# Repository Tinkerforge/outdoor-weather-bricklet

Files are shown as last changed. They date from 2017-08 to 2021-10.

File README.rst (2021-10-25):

Outdoor Weather Bricklet
========================

This repository contains the firmware source code and the hardware design
files. The documentation generator configs can be found at
https://github.com/Tinkerforge/generators

Repository Content
------------------

software/:
 * examples/: Examples for all supported languages
 * build/: Compiled files
 * src/: Source code of firmware
 * Makefile: Makefile to build project

hardware/:
 * Contains KiCad project files and additionally schematics as PDF

datasheets/:
 * Contains datasheets for sensors and complex ICs that are used

Hardware
--------

The hardware is designed with the open source EDA Suite KiCad
(http://www.kicad.org). Before you are able to open the files,
you have to install the Tinkerforge kicad-libraries
(https://github.com/Tinkerforge/kicad-libraries). You can either clone
them directly in hardware/ or clone them in a separate folder and
symlink them into hardware/
(ln -s kicad_path/kicad-libraries project_path/hardware). After that you
can open the .pro file in hardware/ with KiCad and from there view and
modify the schematics and the PCB layout.

Software
--------

If you want to do your own Brick/Bricklet firmware development we highly
recommend that you use our build environment setup script and read the
tutorial (https://www.tinkerforge.com/en/doc/Tutorials/Tutorial_Build_Environment/Tutorial.html).

To compile the C code we recommend you to install the newest GNU Arm Embedded
Toolchain (https://launchpad.net/gcc-arm-embedded/+download).
You also need to install bricklib2 (https://github.com/Tinkerforge/bricklib2).

You can either clone it directly in software/src/ or clone it in a
separate folder and symlink it into software/src/
(ln -s bricklib_path/bricklib2 project_path/software/src/). Finally make sure to
have CMake installed (http://www.cmake.org/cmake/resources/software.html).

After that you can build the firmware by invoking make in software/.
The firmware (.zbin) can then be found in software/build/ and uploaded
with brickv (click button "Flashing" on start screen).

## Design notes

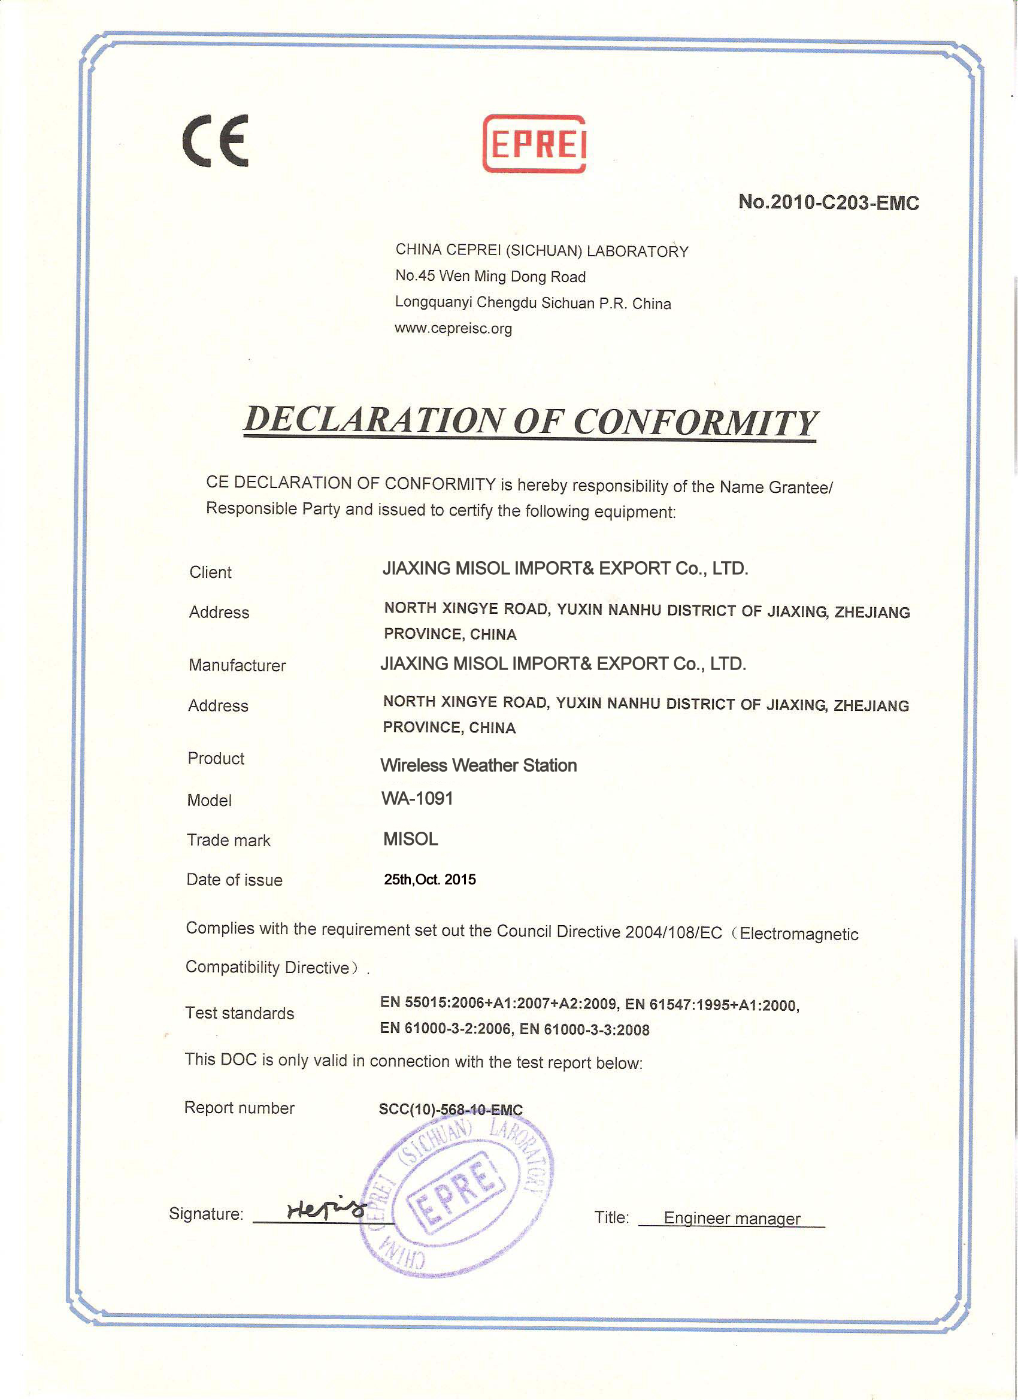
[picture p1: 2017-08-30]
datasheets/CE.jpg

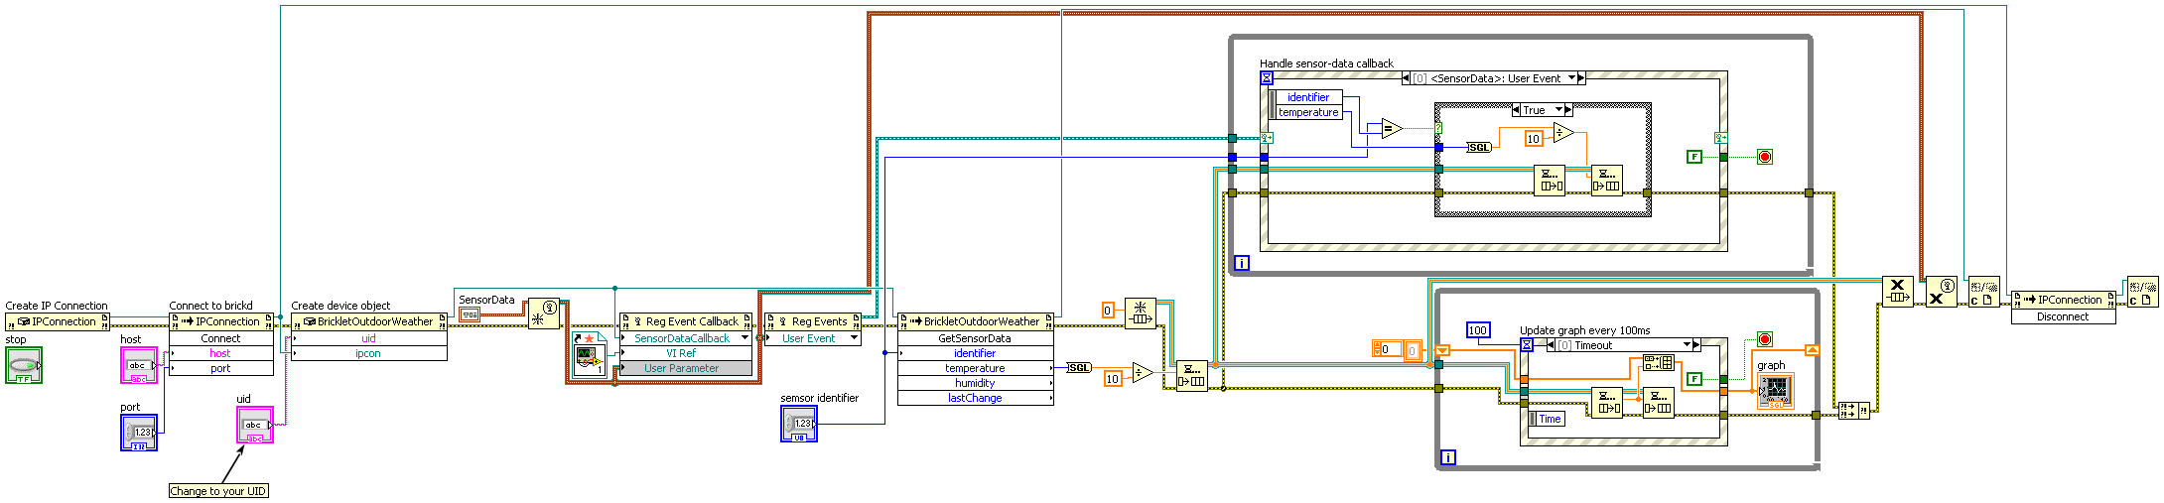
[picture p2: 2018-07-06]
software/examples/labview/Example Graph.vi.png

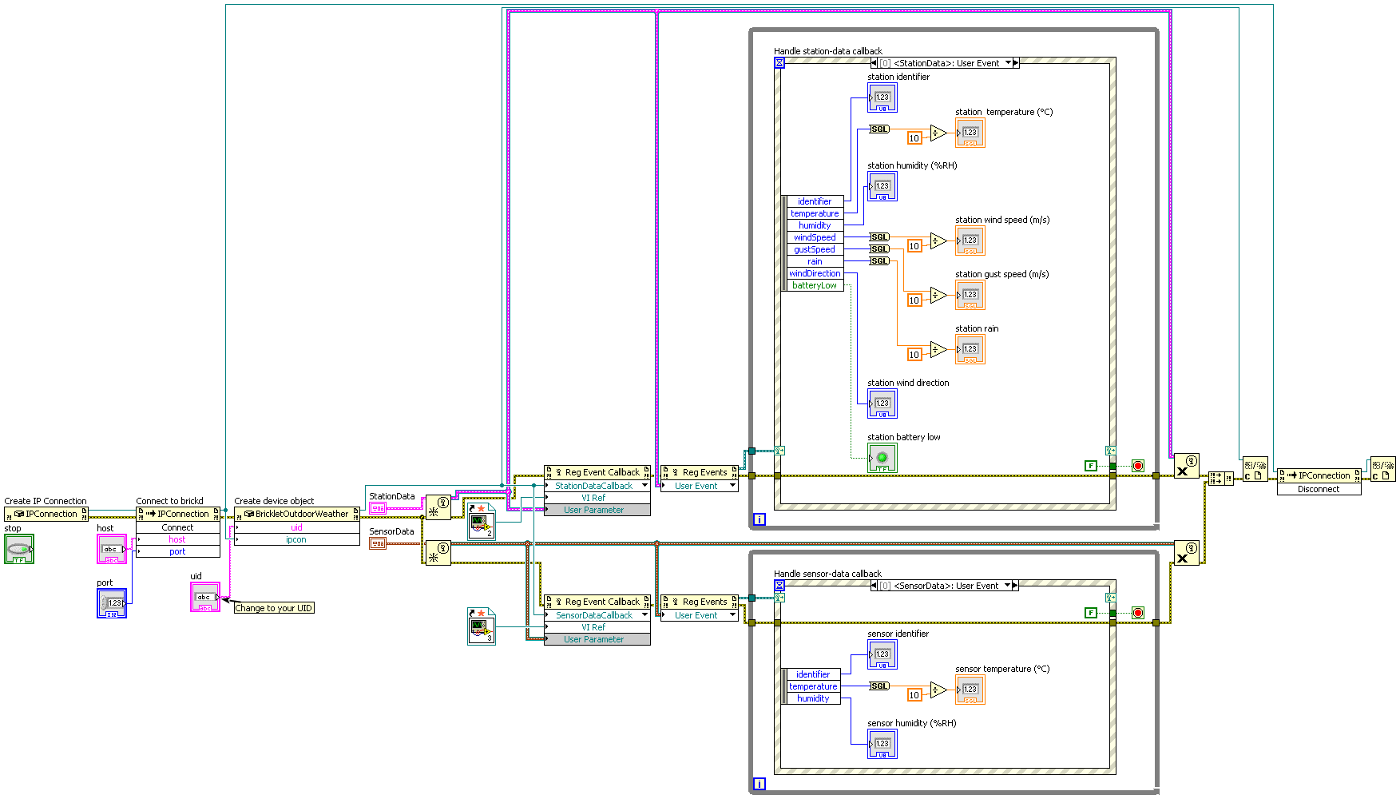
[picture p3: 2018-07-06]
software/examples/labview/Example Callback.vi.png

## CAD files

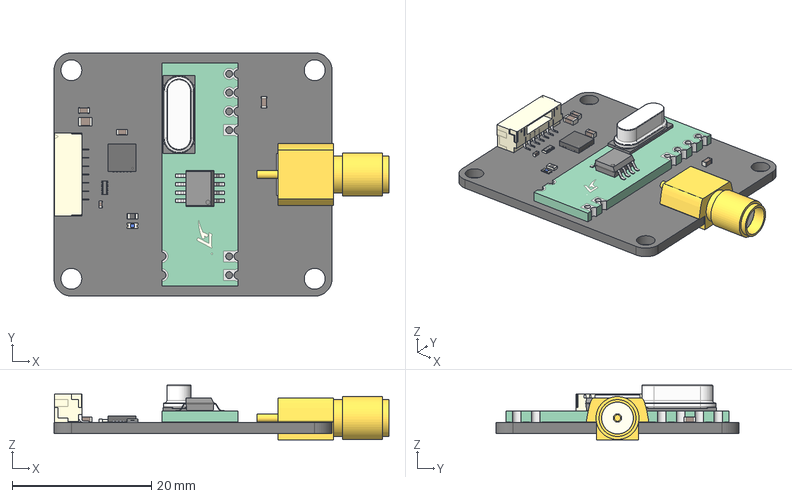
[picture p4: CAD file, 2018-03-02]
hardware/outdoor-weather.step
48.2 x 35.0 x 7.89 mm

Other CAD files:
hardware/outdoor-weather.FCStd

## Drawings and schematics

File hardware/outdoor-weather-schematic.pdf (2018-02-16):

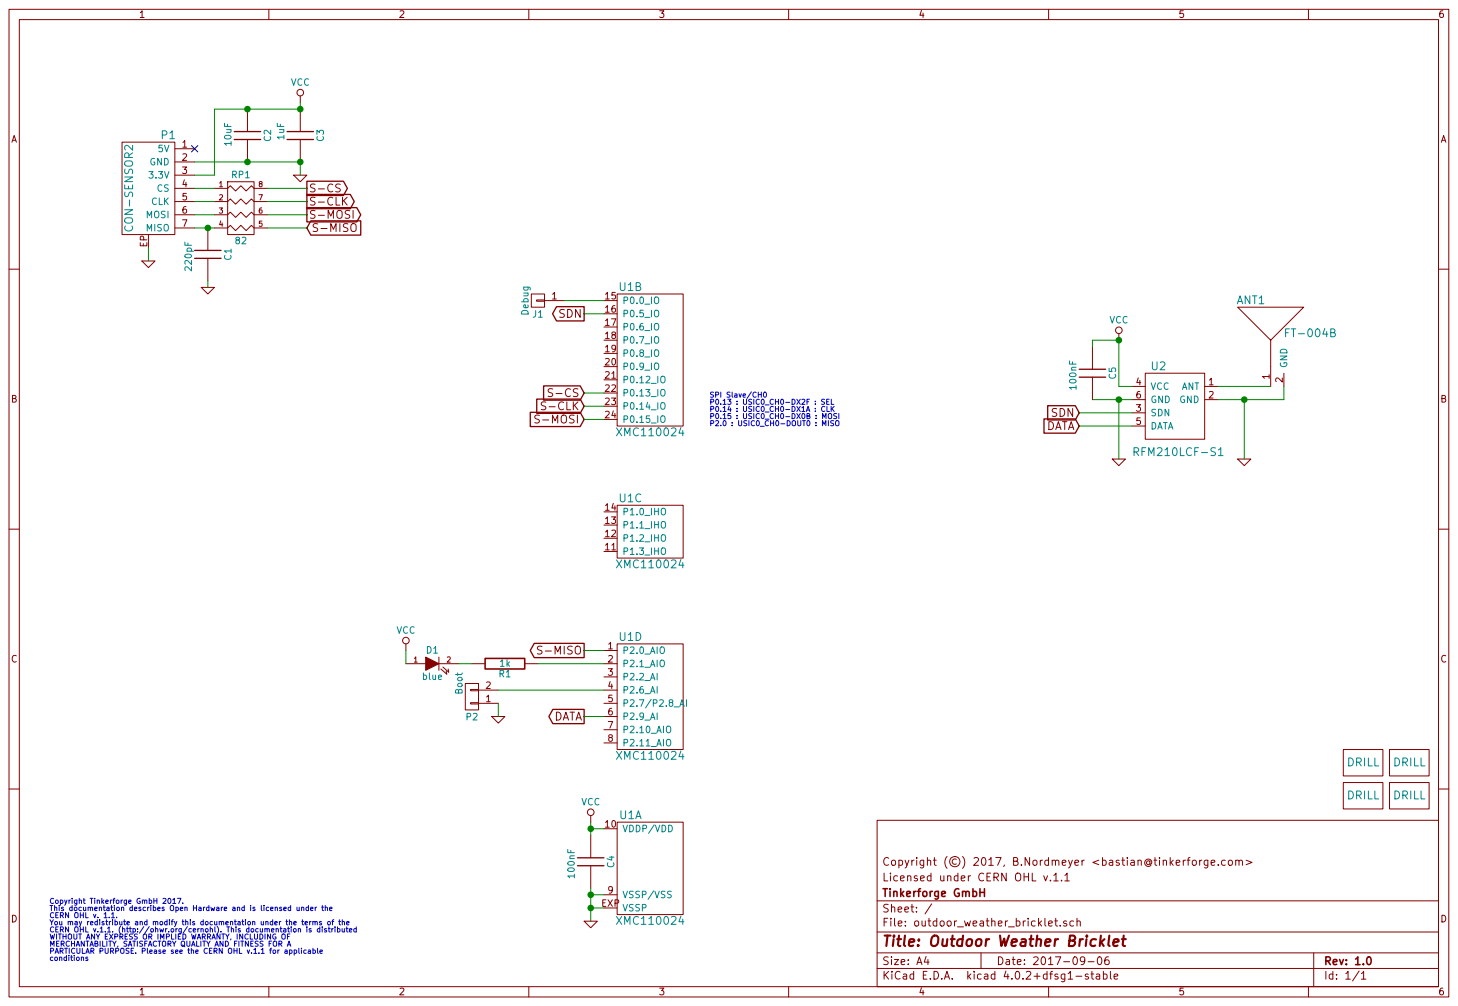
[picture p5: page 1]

SPI Slave/CH0 P0.13 : USIC0_CH0-DX2F : SEL P0.14 : USIC0_CH0-DX1A : CLK

Licensed under CERN OHL v.1.1 Copyright (©) 2017, B.Nordmeyer <bastian@tinkerforge.com>

File: outdoor_weather_bricklet.sch Sheet: / Tinkerforge GmbH

Copyright Tinkerforge GmbH 2017. This documentation describes Open Hardware and is licensed under the CERN OHL v. 1.1. You may redistribute and modify this documentation under the terms of the CERN OHL v.1.1. (http://ohwr.org/cernohl). This documentation is distributed WITHOUT ANY EXPRESS OR IMPLIED WARRANTY, INCLUDING OF MERCHANTABILITY, SATISFACTORY QUALITY AND FITNESS FOR A

Id: 1/1 Title: Outdoor Weather Bricklet

PARTICULAR PURPOSE. Please see the CERN OHL v.1.1 for applicable
conditions

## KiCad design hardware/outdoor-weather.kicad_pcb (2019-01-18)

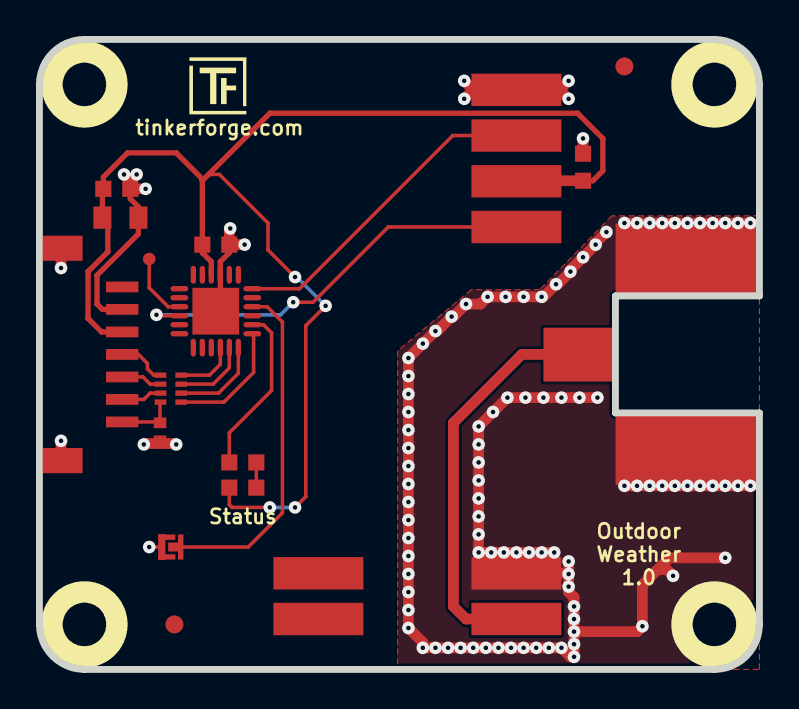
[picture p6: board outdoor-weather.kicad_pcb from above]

Board: 2 copper layers, 40.0 x 35.0 mm, 22 parts (0 on the bottom side), 17 nets.

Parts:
ANT1: FT-004B
C1: 220pF; C0402F
C2: 10uF; C0805
C3: 1uF; C0603F
C4, C5: 100nF; C0603F
D1: blue; D0603F
Fiducial_Mark: VAL**; Fiducial_Mark
Fiducial_Mark#2: VAL**; Fiducial_Mark
J1: Debug; DEBUG_PAD
P1: CON-SENSOR2
P2: Boot; SolderJumper
R1: 1k; R0603F
RP1: 82; 4X0402
U1: XMC110024; QFN24-4x4mm-0.5mm
U2: RFM210LCF-S1
U4, U5, U6, U7: DRILL; DRILL_NP
VAL: CE_5mm
VAL#2: WEEE_7mm

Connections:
DATA: U1.6, U2.5
GND: ANT1.2, C1.1, C2.1, C3.1, C4.1, C5.1, P1.2, P1.EP, P2.1, U1.9, U1.EXP, U2.2, U2.6
unnamed: ANT1.1, U2.1
unnamed: C1.2, P1.7, RP1.4
unnamed: D1.2, R1.2
unnamed: J1.1, U1.15
unnamed: P1.4, RP1.1
unnamed: P1.5, RP1.2
unnamed: P1.6, RP1.3
unnamed: P2.2, U1.4
unnamed: R1.1, U1.2
S-CLK: RP1.7, U1.23
S-CS: RP1.8, U1.22
S-MISO: RP1.5, U1.1
S-MOSI: RP1.6, U1.24
SDN: U1.16, U2.3
VCC: C2.2, C3.2, C4.2, C5.2, D1.1, P1.3, U1.10, U2.4

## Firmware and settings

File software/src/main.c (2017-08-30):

/* outdoor-weather-bricklet
 * Copyright (C) 2017 Olaf Lüke <olaf@tinkerforge.com>
 *
 * main.c: Initialization for Outdoor Weather Bricklet
 *
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
 * You should have received a copy of the GNU Lesser General Public
 * License along with this library; if not, write to the
 * Free Software Foundation, Inc., 59 Temple Place - Suite 330,
 * Boston, MA 02111-1307, USA.
 */

#include <stdio.h>
#include <stdbool.h>

#include "configs/config.h"

#include "bricklib2/bootloader/bootloader.h"
#include "bricklib2/hal/system_timer/system_timer.h"
#include "bricklib2/logging/logging.h"
#include "communication.h"
#include "rfm210.h"

RFM210 rfm210;

int main(void) {
	logging_init();
	logd("Start Outdoor Weather Bricklet\n\r");

	communication_init();
	rfm210_init(&rfm210);

	uint32_t t = system_timer_get_ms();

	while(true) {
		if(system_timer_is_time_elapsed_ms(t, 1000)) {
//			logd("time: %d\n\r", t);
			t = system_timer_get_ms();
		}

		bootloader_tick();
		communication_tick();
		rfm210_tick(&rfm210);
	}
}

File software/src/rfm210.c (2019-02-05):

/* outdoor-weather-bricklet
 * Copyright (C) 2017 Olaf Lüke <olaf@tinkerforge.com>
 *
 * rfm210.c: RFM210 driver
 *
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
 * You should have received a copy of the GNU Lesser General Public
 * License along with this library; if not, write to the
 * Free Software Foundation, Inc., 59 Temple Place - Suite 330,
 * Boston, MA 02111-1307, USA.
 */

#include "rfm210.h"

#include <stdint.h>

#include "configs/config_rfm210.h"
#include "bricklib2/logging/logging.h"

#include "xmc_gpio.h"
#include "xmc_eru.h"
#include "xmc_ccu4.h"

#include "communication.h"

// Wait for 12h for a packet until we delete a weather station/sensor
#define RFM210_MAX_WAIT (1000*60*60*12)

// OOK format:
// High:   |^|__| -> 500us  | 1000us
// Low:  |^^^|__| -> 1500us | 1000us


#define RFM210_TIME_DELTA   15 // We allow for a time delta of 150us
#define RFM210_OOK_ON_HIGH  50 // OOK on-time for high is 500us
#define RFM210_OOK_ON_LOW  150 // OOK on-time for low is 1500us
#define RFM210_OOK_OFF     100 // OOK off-time is 1000us (for low and high)


#define rfm210_recv_handler IRQ_Hdlr_3

extern RFM210 rfm210;
void __attribute__((optimize("-O3"))) __attribute__ ((section (".ram_code"))) rfm210_recv_handler(void) {
	// Always write changes from low to high in even array index
	// and changes from high to low in odd array index.
	// If the edge changed too fast for the interrupt, we will fill the missed
	// index up with the current time too.
	if(( XMC_GPIO_GetInput(RFM210_RECV_PIN) && (  rfm210.timestamp_end & 1)) ||
	   (!XMC_GPIO_GetInput(RFM210_RECV_PIN) && (!(rfm210.timestamp_end & 1)))) {
		rfm210.timestamps[rfm210.timestamp_end] = CCU40_CC41->TIMER;
		rfm210.timestamp_end = (rfm210.timestamp_end+1) & RFM210_TIMESTAMP_MASK;
	}
	rfm210.timestamps[rfm210.timestamp_end] = CCU40_CC41->TIMER;
	rfm210.timestamp_end = (rfm210.timestamp_end+1) & RFM210_TIMESTAMP_MASK;
}

bool rfm210_check_station_timeout(const uint8_t id) {
	if(system_timer_is_time_elapsed_ms(rfm210.payload_station_last_change[id], RFM210_MAX_WAIT)) {
		rfm210.payload_station_last_change[id] = 0;
		return true;
	}

	return false;
}

bool rfm210_check_sensor_timeout(const uint8_t id) {
	if(system_timer_is_time_elapsed_ms(rfm210.payload_sensor_last_change[id], RFM210_MAX_WAIT)) {
		rfm210.payload_sensor_last_change[id] = 0;
		return true;
	}

	return false;
}

static uint8_t rfm210_crc8(const uint8_t *data, const uint8_t length) {
	uint8_t crc = 0;

	for(uint8_t i = 0; i < length; i++) {
		uint8_t byte = data[i];
		for(uint8_t j = 0; j < 8; j++) {
			bool mix = (crc ^ byte) & 0x80;
			crc <<= 1;
			if(mix) {
				crc ^= 0x31;
			}
			byte <<= 1;
		}
	}

	return crc;
}

static void rfm210_print_packet_station(RFM210PacketStation *packet, uint8_t id) {
	logd("RFM210 station packet (%d):\n\r", id);
	logd(" temperature:          %u\n\r", packet->temperature);
	logd(" humidity:             %u\n\r", packet->humidity);
	logd(" wind_speed:           %u\n\r", packet->wind_speed);
	logd(" gust_speed:           %u\n\r", packet->gust_speed);
	logd(" rain                  %u\n\r", packet->rain);
	logd(" battery_low:          %u\n\r", packet->battery_low);
	logd(" wind_direction:       %u\n\r", packet->wind_direction);
	logd("\n\r");
}

static void rfm210_print_packet_sensor(RFM210PacketSensor *packet, uint8_t id) {
	logd("RFM210 sensor packet (%d):\n\r", id);
	logd(" temperature:          %u\n\r", packet->temperature);
	logd(" humidity:             %u\n\r", packet->humidity);
	logd("\n\r");
}

static void rfm210_reset(RFM210 *rfm210) {
	memset(rfm210->data, 0, RFM210_DATA_SIZE);

	rfm210->data_index = 0;
	rfm210->data_bit   = 1;
	rfm210->data[0]    = 1 << 7;
}

static uint32_t rfm210_get_next_timestamp_index(RFM210 *rfm210, uint32_t index) {
	return (index + 1) & RFM210_TIMESTAMP_MASK;
}

#define NIBBLE_LOW(value) ((value >> 4) & 0xF)
#define NIBBLE_HIGH(value) (value & 0xF)
static void rfm210_check_data_station(RFM210 *rfm210) {
//	logd("data ws: "); log_array_u8(rfm210->data, 11, true);
//	logd("crc: %d\n\r", rfm210_crc8(&rfm210->data[1], 9));

	// Check preamble, family code and CRC
	if((rfm210->data[0] != 0xFF) ||
	   ((rfm210->data[1] >> 4) != RFM210_STATION_FAMILY_CODE) ||
	   (rfm210_crc8(&rfm210->data[1], 9) != rfm210->data[10])) {
		return;
	}

	const uint8_t id = (NIBBLE_HIGH(rfm210->data[1]) << 4) | NIBBLE_LOW(rfm210->data[2]);

	memcpy(&rfm210->payload_station[id][0], &rfm210->data[2], 8);
	rfm210->payload_station_last_change[id] = system_timer_get_ms();

	// Testing
	RFM210PacketStation packet;
	rfm210_fill_packet_station(rfm210, id, &packet);
	rfm210_print_packet_station(&packet, id);
}

static bool rfm210_check_data_sensor(RFM210 *rfm210) {
//	logd("data ht: "); log_array_u8(rfm210->data, 7, true);
//	logd("crc: %d\n\r", rfm210_crc8(&rfm210->data[1], 4));

	// Check preamble, family code and CRC
	if((rfm210->data[0] != 0xFF) ||
	   ((rfm210->data[1] >> 4) != RFM210_SENSOR_FAMILY_CODE) ||
	   (rfm210_crc8(&rfm210->data[1], 4) != rfm210->data[5])) {
		return false;
	}

	const uint8_t id = (NIBBLE_HIGH(rfm210->data[1]) << 4) | NIBBLE_LOW(rfm210->data[2]);

	memcpy(&rfm210->payload_sensor[id][0], &rfm210->data[2], 3);
	rfm210->payload_sensor_last_change[id] = system_timer_get_ms();

	// Testing
	RFM210PacketSensor packet;
	rfm210_fill_packet_sensor(rfm210, id, &packet);
	rfm210_print_packet_sensor(&packet, id);

	return true;
}

void rfm210_fill_packet_station(RFM210 *rfm210, const uint16_t id, RFM210PacketStation *packet) {
	uint8_t *data = &rfm210->payload_station[id][0];

	packet->temperature       = ((NIBBLE_HIGH(data[0]) & 0x3) << 8) | (NIBBLE_LOW(data[1])  << 4) |  NIBBLE_HIGH(data[1]);
	packet->humidity          = (NIBBLE_LOW(data[2]) << 4)          |  NIBBLE_HIGH(data[2]);
	packet->wind_speed        = (NIBBLE_LOW(data[3]) << 4)          |  NIBBLE_HIGH(data[3]);
	packet->gust_speed        = (NIBBLE_LOW(data[4]) << 4)          |  NIBBLE_HIGH(data[4]);
	packet->rain              = (NIBBLE_LOW(data[5]) << 12)         | (NIBBLE_HIGH(data[5]) << 8) | (NIBBLE_LOW(data[6]) << 4) | NIBBLE_HIGH(data[6]);
	packet->battery_low       =  NIBBLE_LOW(data[7]) & (1 << 0);
	packet->wind_direction    =  NIBBLE_HIGH(data[7]);


	// TODO: What are these temperature flags and how can we handle them?
//	bool temperature_flag1    = NIBBLE_HIGH(rfm210->data[2]) & (1 << 3);
//	bool temperature_flag2    = NIBBLE_HIGH(rfm210->data[2]) & (1 << 2);
	bool wind_direction_error =  NIBBLE_LOW(data[7]) & (1 << 3);

	// Handle wind direction errors
	if(wind_direction_error || (packet->wind_direction > OUTDOOR_WEATHER_WIND_DIRECTION_NNW)) {
		packet->wind_direction = OUTDOOR_WEATHER_WIND_DIRECTION_ERROR;
	}

	// Convert values to proper SI units, humidity is already in %rel
	packet->temperature = packet->temperature - 400; // °C/10
	packet->wind_speed  = packet->wind_speed*340/100; // m/10s
	packet->gust_speed  = packet->gust_speed*340/100; // m/10s
	packet->rain        = packet->rain*30/10;         // mm/10
}
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

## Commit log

2017-08-30 Initial commit
    At this point data is already received properly from weather station
    and printed with uartbb output
    [cmake_config_custom.txt]
2017-08-30 Save data for all 256 weather station device ids
2017-09-06 hardware files for outdoor weather bricklet, pcb only copy of motion detector
    [outdoor_weather_bricklet.kicad_pcb, outdoor_weather_bricklet.sch]
2017-09-08 briklet finished
    [outdoor_weather_bricklet.kicad_pcb, outdoor_weather_bricklet.sch]
2017-09-08 remove silkscreen layers from footprints
    [outdoor_weather_bricklet.kicad_pcb]
2017-09-28 Switch MCU from 1400 to 1100
    [cmake_config_custom.txt]
2017-09-29 add status led text
    [outdoor_weather_bricklet.kicad_pcb]
2017-10-26 specify processor type
    [outdoor_weather_bricklet.kicad_pcb, outdoor_weather_bricklet.sch]
2017-11-03 Add support for simultaneous station/sensor usage
2018-02-05 Add 3d information (final)
    [outdoor_weather_bricklet.kicad_pcb, outdoor_weather_bricklet.sch]
2018-02-05 Add 3d model (*.step & *.FCStd)
    [outdoor_weather_bricklet.FCStd, outdoor_weather_bricklet.step]
2018-02-16 Minor optical adjustments
    [outdoor_weather_bricklet.sch]
2018-02-16 Add schematic (PDF)
2018-02-20 Cleanup KiCad libraries config
    Ensure LibDir=kicad-libraries and LibName1=tinkerforge.
    Remove special library.
2018-02-28 Add new 3d model with more detailed components
    [outdoor_weather_bricklet.FCStd, outdoor_weather_bricklet.kicad_pcb, outdoor_weather_bricklet.step]
2018-03-02 Fix outline from antenna connector larger caused thru production tolerance
    [outdoor_weather_bricklet.kicad_pcb]
2018-05-11 Rename files
    [outdoor-weather.FCStd, outdoor-weather.kicad_pcb, outdoor-weather.sch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]
2018-06-18 Change capacitor footprint(s) to C0402F
    [outdoor-weather.kicad_pcb, outdoor-weather.sch]
2018-12-14 go: Fix printf parameters.
2018-12-20 Fix constant handling in examples.
    [example_callback.c]
2019-02-05 Remove Station/Sensor from list of identifiers after 12h with no data
2019-05-29 Disallow SPITFP interrupt to disable IRQs
    The newest version of bricklib2 disables IRQs during SPITFP
    transfers by default. This needs to be turned off for this
    Bricklet since it has higher priority IRQs that can not wait.
    For this we set the SPITFP_NOT_ALLOWED_TO_DISABLE_IRQ define.
2019-06-06 Increase minimum gap between messages to filter duplicates.
2019-08-22 c: Adapt to bindings changes
    [example_callback.c]
2020-08-31 uc: Use fixed-with placeholders in format strings.
    [example_callback.c]
2020-09-02 uc: Add example driver note.
2020-10-16 uc: Fix divisor type.
    [example_callback.c]
2021-10-25 Update KiCad link
    https://www.kicad.org/blog/2021/10/Avoid-links-to-former-kicad-domain/
2022-04-27 uc: Adapt to bindings changes
    [example_callback.c]
